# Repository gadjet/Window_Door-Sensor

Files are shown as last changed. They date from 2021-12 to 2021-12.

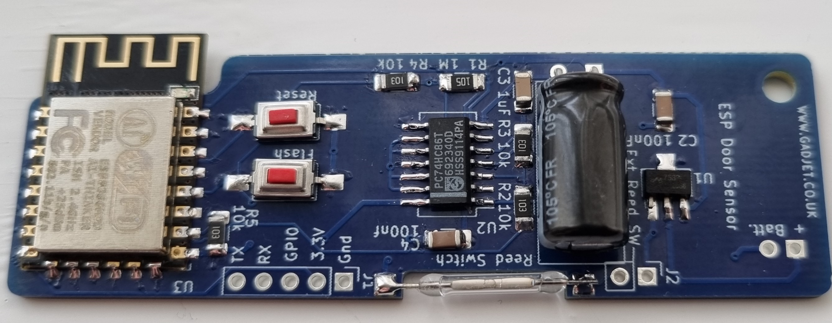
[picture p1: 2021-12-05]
2021-11-18 14.43.48.jpg

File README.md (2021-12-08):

# Window_Door-Sensor
Door/Window sensor based on a design by MakerMeik but using different code to use the ESP-NOW protocol.

Using ESP-NOW means that the connection and sending of the data packet takes around 500mS to complete and
is device to device without the need of a WiFi router.

There are two Arduino ino files, one for the transmitter and one for the receiver, the receiver will need to
be powered up to receive data and the recieved data will be sent to the host computer via serial/USB to be read
in a terminal program.

There is an additiona png file showing the Scope trace of the power consumption profiile, although this shows the length to be 626mS it is usually around 526mS.

Using an online calculator to work out how long a battery would last with a couple of triggers an hour you can get well over a year on a 600mAH battery.

On the rear half of the 3D printed case I used M3 Brass threaded inserts for the M3 cap screws to thread into.

More information can also be found on www.gadjet.co.uk

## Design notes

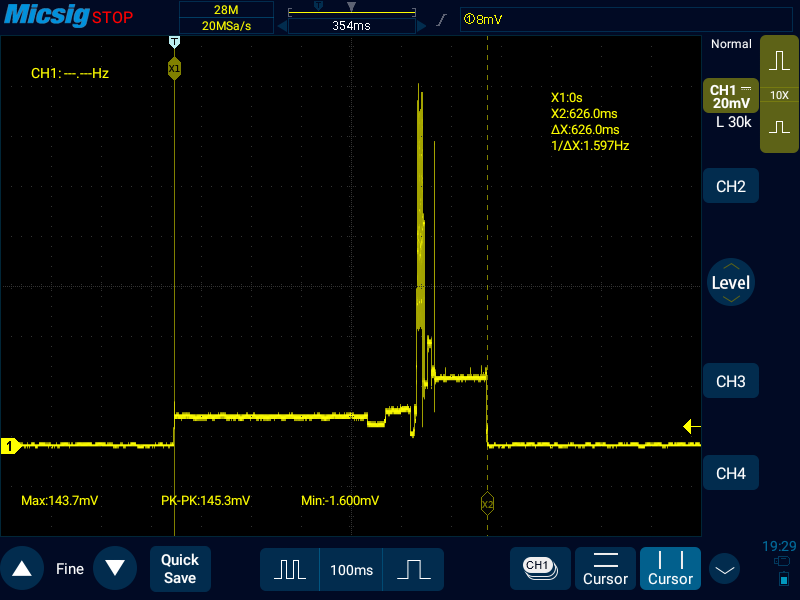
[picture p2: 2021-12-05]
Screenshot_2021-12-01-19-30-01.png

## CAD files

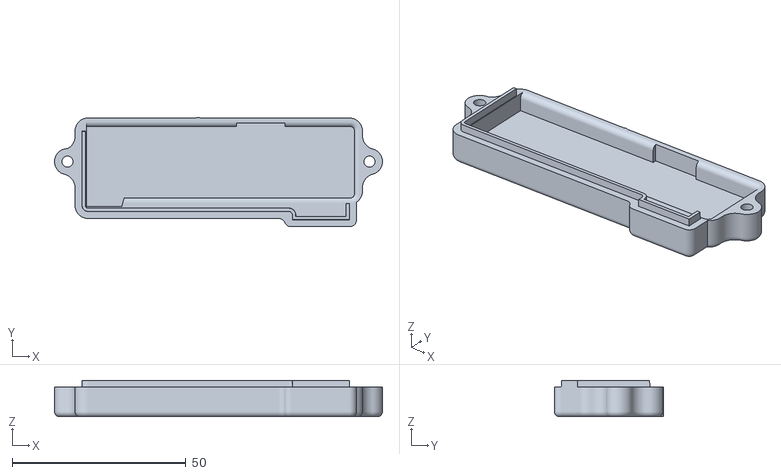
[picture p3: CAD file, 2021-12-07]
Door Sensor Ver 1.00 Smaller Rear half.stl
94.5 x 31.5 x 10.5

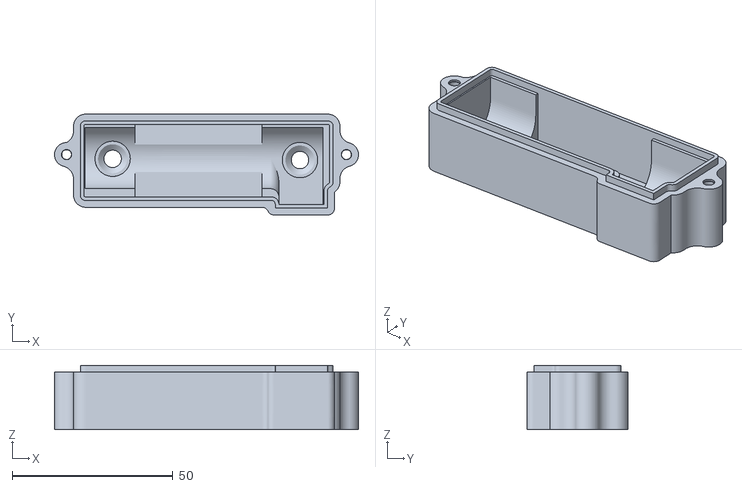
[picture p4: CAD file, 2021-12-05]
Door Sensor Ver 1.00 Rear half.stl
94.5 x 31.3 x 20.0

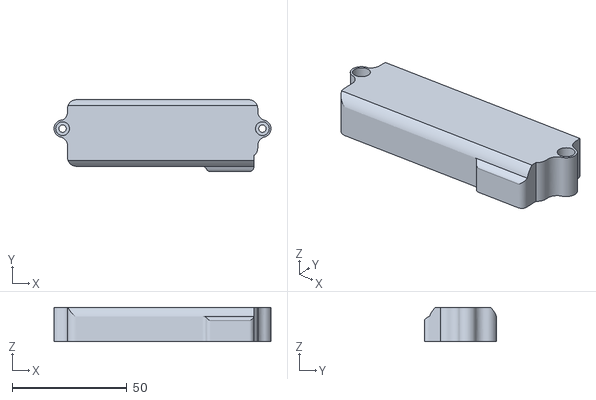
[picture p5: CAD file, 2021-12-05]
Door Sensor Ver 1.00 Front half.stl
94.5 x 31.5 x 15.0

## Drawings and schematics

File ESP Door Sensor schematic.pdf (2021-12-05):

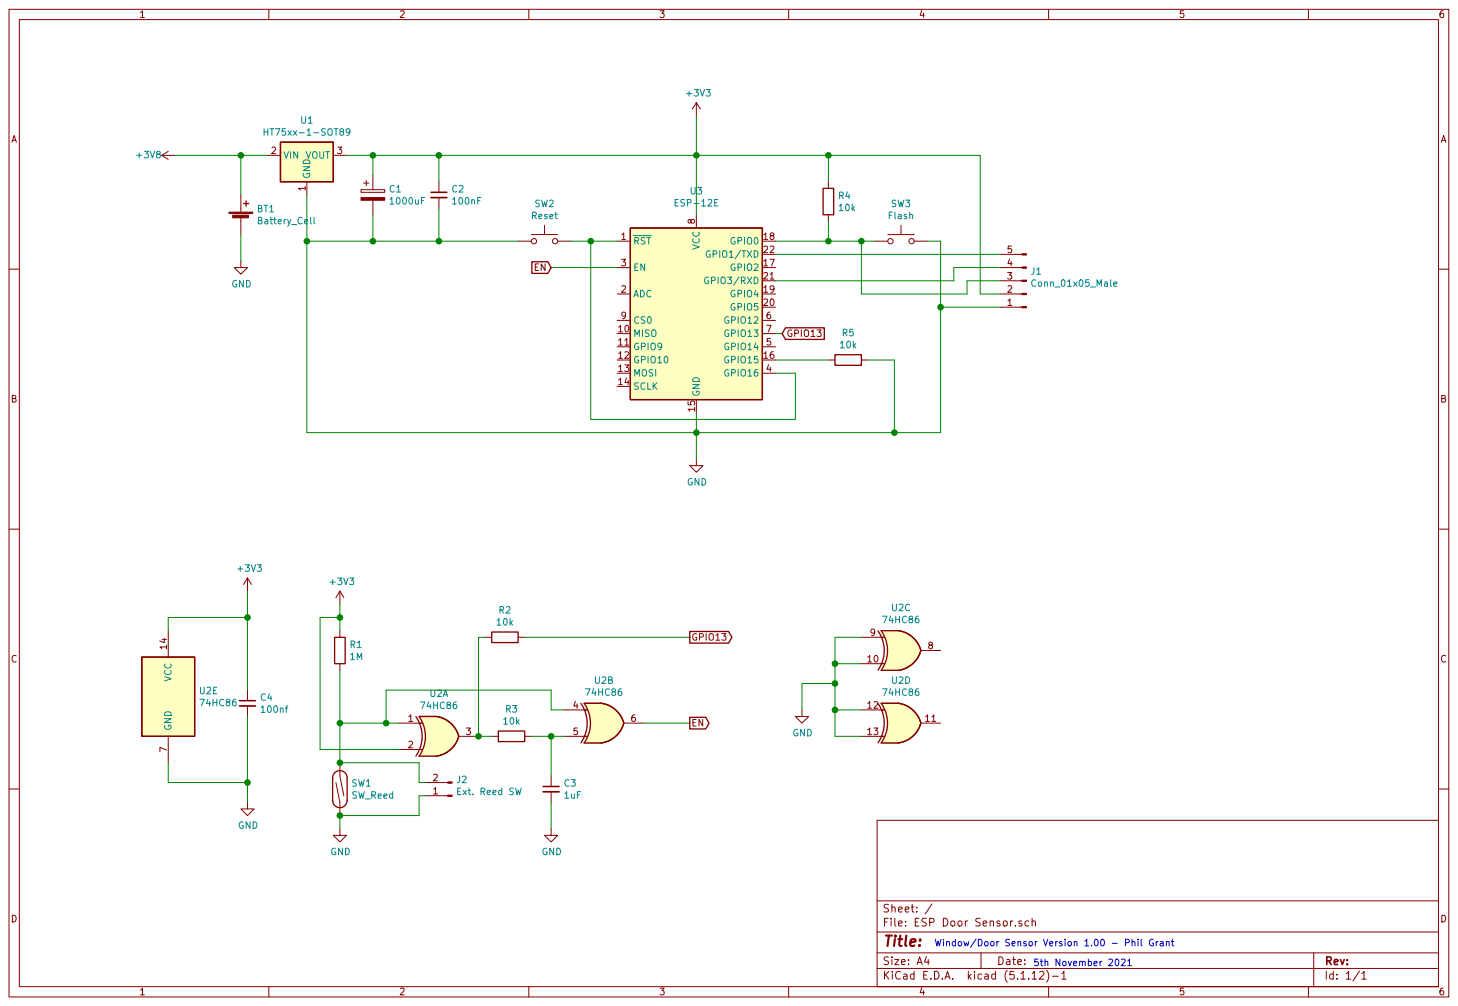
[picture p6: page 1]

Id: 1/1 Title: File: ESP Door Sensor.sch Sheet: /

5th November 2021 Window/Door Sensor Version 1.00 - Phil Grant

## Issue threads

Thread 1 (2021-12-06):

Great improvement!

MakerMeik, 2021-12-06:
Hi Gadjet,

unfortunately, Youtube occasionally eats comments, but I found the reference to your completed project in the email notification and am thrilled. I've pinned a corresponding link in the comments of my video.

Thanks for sharing your ideas and additions. I do my videos for people like you: Knowledge doubles when you share it. :-)

gadjet, 2021-12-07:
Thanks, I have a nother design using a step-up booster so it can use a 1.5V battery and it's a lot smaller.

Closed 2021-12-07.

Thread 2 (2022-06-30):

Is this hardware issue like capacitor blown or so?

sheminasalam, 2022-06-30:
Hi there I have an issue with version 1 of this sensor. It would be good if you could help me out with it. My sensor can detect when the window is open without any issues. But when it comes to closing, it wont work all the time. I tried to diagnose the issue with serial monitor and found that when the window is being closed, the esp8266 starts to wake but before executing any functions, it hangs up. One more thing I noticed is that when this problem occurs the onboard led won't even blink like when the board boots up. But when we push the reset button(GPIO16) in closed state, the device boots fine and completes action and sleeps.

Is this a code issue or some hardware issue? what can be the issue? I am confused because majority of the time this works fine.

gadjet, 2022-06-30:
With version 1 it does need a good capacitor, i got away with using a 220uF capacitor but I would recommend starting with 1000uF and making sure it works OK then redcuing it and testing.  A lot of issues with ESPs can be traced to lack of power supply.
Some general questions to narrow it down: -
 - How are you powering it
 - what size capacitor are you using
 - are you using the same LDO as I did
 - did you make the PCB or is it on a breadboard?

DO you have access to an oscilloscope to monitor the supply voltage at the ESP device?

gadjet, 2022-06-30:
OK one issue is the regulator, do you mean the the ams1117 ? if so this regulator isn't a low voltage drop regulator and can drop over 1V when supplying the ESP during transmission, not good enough for using with a single L-Ion cell.

Also there are many FTDI connectors that are not upto supplting a good voltage for the ESP but it would probably be OK, the only way to rule the supply out as a problem would be to have an oscilloscope across the ESP VCC and ground.

Could you add a photograph of you device?
Are you using the PCB design I added to the project?

gadjet, 2022-06-30:
Also what size Capacitor are you using?

sheminasalam, 2022-07-01:
Yes, I am using ams1117 .
I am using exactly the same circuit but instead of instead smd components I have through hole. I will upload a pic soon.

The USB to ttl converter that I have used was working fine with all other devices. So chances of it being faulty is very less.

I am using 100nf capacitors as your circuits.

The strange thing is that this only appears when the door is being closed. Can you explain to me how the device deepsleep is reset and device is booted when the door is closed?

sheminasalam, 2022-07-01:
As you advised, I changed my power supply from 18650 to lipo and now I believe the issue is sorted. But then again I have multiple such sensors which are using 18650 without any issues.

BTW I use your exact circuit but with the exception that the capacitors are through hole type and so pcb has such changes.

gadjet, 2022-07-01:
GLad you got it working but I would really recommend changing your regulator to a low dropout type because if you are using a battery then the voltage will naturally fall over time and you will get the problem back due to the high voltage drop of the regulator the AMS1117 is only really useful with a 5V fixed DC supply to 3.3V not for use with batteries, I would use the HT7533 as in the circuit diagram or something similar.
The HT7533 has a dropout voltage of around 80mV instead of the AMS1117's of around 1V.

sheminasalam, 2022-07-01:
Ok, I will try to change my sensors to version 5. Thanks

Closed 2022-07-01.

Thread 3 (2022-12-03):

Device not reseting when when door is closing

sheminasalam, 2022-12-03:
Hi there, we have talked before of this same issue and you gave me pointers to sort it then but now it has again happened. Hope you can help me now also.

This is my pcb. The circuit is the same but I coverted it to hole through components as i am not expert with smd.

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

I am using HT7333 LDO now with 1000uf capacitor for ESP(in PCB its shown as 100nf) and 100nf between ground and SN74HC86N.
Battery is 18560

The issue that the device doesnot update when door is closed. I tried to debug it with the limited tools I have found it was not a software thing as the led on the esp8266 board doesn't even light up when closing. On further investigation I found that when closing the GPIO 13 pin pulled high also but the Enable pin of esp is not grounded.

what is the purpose of the 2nd 100nf capacitor? should I try a more powerful capacitor instead of 100nf.

Can you give some pointers?

gadjet, 2022-12-03:
Hi,
Do you have the circuit diagram? the PCB is quite difficult to follow.

gadjet, 2022-12-03:
Are the values shown on the PCB components correct, the 100nF above the battery connector should be 1uF not 100nF.

sheminasalam, 2022-12-03:
I was using 100nf, will change to 1uf and see if anything changes

I don't have the circuit diagram as I assembled looking from your pcb and circuit.

sheminasalam, 2022-12-03:
I dont have 1uf in stock. Will it be ok if I use 10uf?

gadjet, 2022-12-03:
That capacitor determines the pulse 10uf should be OK but I can't be sure, you could try an online simulation to see the difference.
The 1M Resistor pull up can be swapped for a 10k but it will increase the quiescent current.
One suggestion is the PCB should really have thicker supply tracks to the ESP, ideally GND and VCC power planes should be used.

gadjet, 2022-12-03:
When you look at the enable pin it only gets toggled very quickly to wake up the ESP each time the switch is opened or closed, you would need an oscilloscope to monitor it.

sheminasalam, 2022-12-03:
I will try with simulation.

To thicken the supply track, in this case I will use a 1mm single core wire to connect the vcc and gnd directly to esp12f. Hope that woud give an additional route for power. I will certainly keep the use of gnd and vcc planes in my next designing.

Thanks. Appreciate the timely response. Will update with the results...

Closed 2022-12-04.

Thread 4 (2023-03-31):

Esp8266 battery operated smoke alarm

sheminasalam, 2023-03-31:
First, please accept my appologies for opening an issue but i didn't have any other discusions open in your threads. I want to know if it would be possible to design a battery(18650) operated smoke sensor(MQ2 sensor module) with esp8266. The thing is that there are many tutorials which work on DC supply. There is one which hacks a [traditional smoke detector ](https://www.youtube.com/watch?v=7ZcnPoZn_O0) but not MQ2 sensor module. How would the circuit look like for max battery savings.

gadjet, 2023-04-08:
Hi, try this page?
If the MOS gives a positive thrigger when there is smoke it could be used to trigger the Version 5 module, also on my github, although the MOS will need to be permenantly powered up.

gadjet, 2023-04-08:
The sensor will consume around 160mA so not a good candidate for battery power unless you have a very big battery

Closed 2023-04-09.

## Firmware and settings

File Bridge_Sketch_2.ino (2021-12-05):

/*
  Based on a sketch form Rui Santos
  Complete project details at https://RandomNerdTutorials.com/esp-now-many-to-one-esp8266-nodemcu/
  Permission is hereby granted, free of charge, to any person obtaining a copy
  of this software and associated documentation files.
  The above copyright notice and this permission notice shall be included in all
  copies or substantial portions of the Software.
*/

#include <ESP8266WiFi.h>
#include <espnow.h>

// Structure example to receive data
// Must match the sender structure
typedef struct struct_message {
  int id;
  char state[7];
  int vBatt;
} struct_message;

// Create a struct_message called myData
struct_message myData;

// Create a structure to hold the readings from each board
struct_message board1;
struct_message board2;

// Create an array with all the structures
struct_message boardsStruct[2] = {board1, board2};

// Callback function that will be executed when data is received
void OnDataRecv(uint8_t * mac_addr, uint8_t *incomingData, uint8_t len) {
  char macStr[18];
  Serial.print("Packet received from: ");
  snprintf(macStr, sizeof(macStr), "%02x:%02x:%02x:%02x:%02x:%02x",
           mac_addr[0], mac_addr[1], mac_addr[2], mac_addr[3], mac_addr[4], mac_addr[5]);
  Serial.println(macStr);
  memcpy(&myData, incomingData, sizeof(myData));
  Serial.printf("Board ID %u: %u bytes\n", myData.id, len);
  Serial.print("Door State: ");
  Serial.println(myData.state);
  Serial.print("Battery Voltage: ");
  Serial.println(myData.vBatt);
}

void setup() {
  // Initialize Serial Monitor
  Serial.begin(115200);

  // Set device as a Wi-Fi Station
  WiFi.mode(WIFI_STA);
  WiFi.disconnect();

  // Init ESP-NOW
  if (esp_now_init() != 0) {
    Serial.println("Error initializing ESP-NOW");
    return;
  }

  // Once ESPNow is successfully Init, we will register for recv CB to
  // get recv packer info
  esp_now_set_self_role(ESP_NOW_ROLE_SLAVE);
  esp_now_register_recv_cb(OnDataRecv);
}

void loop() {
  // Code here

}

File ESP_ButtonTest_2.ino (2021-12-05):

#include<ESP8266WiFi.h>
#include<espnow.h>

uint8_t bridgeAddress[] = {0x2C, 0xF4, 0x32, 0x77, 0x5B, 0x73};   //please update this with the MAC address of your ESP-NOW TO MQTT brigde

// Set your Board ID (ESP32 Sender #1 = BOARD_ID 1, ESP32 Sender #2 = BOARD_ID 2, etc)
#define BOARD_ID 1

const int reedSwitch = 13;

// Structure example to send data
// Must match the receiver structure
typedef struct struct_message {
  int id;
  char state[7];
  int vBatt;
} struct_message;

// Create a struct_message called test to store variables to be sent
struct_message myData;

// Callback when data is sent
void OnDataSent(uint8_t *mac_addr, uint8_t sendStatus) {
  /* Serial.print("\r\nLast Packet Send Status: ");
    if (sendStatus == 0){
     Serial.println("Delivery success");
    }
    else{
     Serial.println("Delivery fail");
    }
  */
}

void setup() {
  // Init Serial Monitor
  //Serial.begin(115200);
  // initialize the reed switch pin as an input:
  pinMode(reedSwitch, INPUT);
  // initialize the wakeup pin as an input:
  pinMode(D0, WAKEUP_PULLUP);
  // Set device as a Wi-Fi Station
  WiFi.mode(WIFI_STA);
  WiFi.disconnect();

  // Init ESP-NOW
  if (esp_now_init() != 0) {
    //Serial.println("Error initializing ESP-NOW");
    return;
  }
  // Set ESP-NOW role
  esp_now_set_self_role(ESP_NOW_ROLE_CONTROLLER);

  // Once ESPNow is successfully init, we will register for Send CB to
  // get the status of Trasnmitted packet
  esp_now_register_send_cb(OnDataSent);

  // Register peer
  esp_now_add_peer(bridgeAddress, ESP_NOW_ROLE_SLAVE, 1, NULL, 0);
}

void loop() {
  // Set values to send
  myData.id = BOARD_ID;
  // Read the state of the reed switch and send open or closed
  if (digitalRead(reedSwitch) == HIGH) {
    strcpy(myData.state, "Closed");
  }
  else {
    strcpy(myData.state, "Open");
  }

  myData.vBatt = analogRead(A0) * 4.2 * 10 / 1023;
  // Send message via ESP-NOW
  esp_now_send(0, (uint8_t *) &myData, sizeof(myData));
  ESP.deepSleep(0);
  delay(200);
}

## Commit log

2021-12-05 Add files via upload
    Gerber files to produce the PCB
2021-12-05 Add files via upload
    STL files for the enclosure
    [Door Sensor Ver 1.00 Front half.stl, Door Sensor Ver 1.00 Rear half.stl]
2021-12-05 Add files via upload
    Assembled PCB Image
2021-12-07 Add files via upload
    Smaller rear half for a flat 600mAH L-Ion Cell
    [Door Sensor Ver 1.00 Smaller Rear half.stl]
